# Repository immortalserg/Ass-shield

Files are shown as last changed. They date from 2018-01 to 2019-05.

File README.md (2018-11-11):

# Ass-shield
## Плата расширения для OrangePi Zero, OrangePi Zero plus, OrangePi Zero plus2, NanoPi Neo, NanoPi Neo Air, NanoPi Neo 2, NanoPi Neo Core, NanoPi Neo Core2, RaspberryPi Zero, BananaPi zero
### Функции
- Массив из 4-х микрофонов через процессор ADAU1772
- RF315/433 МГц приемник/передатчик (м.cx. SYN480R и SYN115)
- NRF24L01+
- zigbee cc2530 + cc2591
- 12 светодиодов WS2812B
- звук i2s ES9023 (только NanoPi) c усилителем 2х3Вт PAM8403 (PAM8404)
- часы реального времени DS3231
- 4 ИК светодиода для управления техникой
- диаметр 80 мм
- поддержска протокола Z-wave (USB stick или UART)
## Описание
- ИК передатчики (4 ИК диода через транзистор) подключены к GPIO26 (PA10) /NanoPi - PA0/
- 433 МГц приемник - GPIO15 (PA03) 
- 433 МГц передатчик - GPIO18 (PA18) /NanoPi PG8/
- 315 МГц приемник - GPIO12 (PA07) /NanoPi PG11/
- 315 МГц передатчик - GPIO16 (PA19) /NanoPi PG9/
- SI4432 - SPI1 (MOSI-GPIO19, MISO-GPIO21, CLK-GPIO23, NIRQ-GPIO13, NSEL-GPIO11)
- nrf24l01+ - SPI1 (MOSI-GPIO19, MISO-GPIO21, CLK-GPIO23, CS-GPIO24) /NanoPi SPI0 (MOSI-PC0, MISO-PC1, CLK-PC2, CS-PC3)/
- zigbee (cc2530) с усилителем cc2591 - UART1
- WS2812 LED - GPIO7 (PA06) 
- Часы реального времени DS3231 - i2c0
- i2c PCF8574 (P0- управление режимом записи 24LC256, P1-P4 - входы ADAU1772, P5 - MUTE  P6&P7 - Gain Select) 

Программирование ADAU1772 через i2c запись на микросхему памяти 24LC256, программирование: цифровые входы микрофонов, выходы аналоговые для OrangePi Zero, для остальных выход i2s в режиме ведомого.

J1 - питание 6-40V (1-VCC, 2-GND) на DC-DC преобразователь

J2 - DEBUG разъем для программирования cc2530 через (1-DC,2-DD,3-Reset,4-3.3V,5-GND)

J3 - питание 5В с DC-DC преобразователя (установить перемычку для питания через DC-DC преобразователь)

J4 - UART2 (1-3.3V, 2-RX, 3-TX, 4-GND) /нет для RaspberryPi Zero/

J5 - антенна NRF24L01+

J6 - i2s (1-WS, 2-CLK, 3-DIN) ADAU1772

J7 - выход на динамики (1-L+, 2-L-, 3-R+, 4-R-)

J8 - антенна zigbee (cc2530+cc2591)

### Переходная плата NanoPi Neo

J1 - переключение выхода звука 1,2-ON;3,4-OFF -- LINE / 1,2-OFF;3,4-ON -- i2s ES9023

### Переходная плата BananaPi zero, RaspberryPi Zero

J3 - переключатель i2s BananaPi Zero / RaspberryPi Zero

Для RaspberryPi Zero не используется LAN и UART2

## Изображения

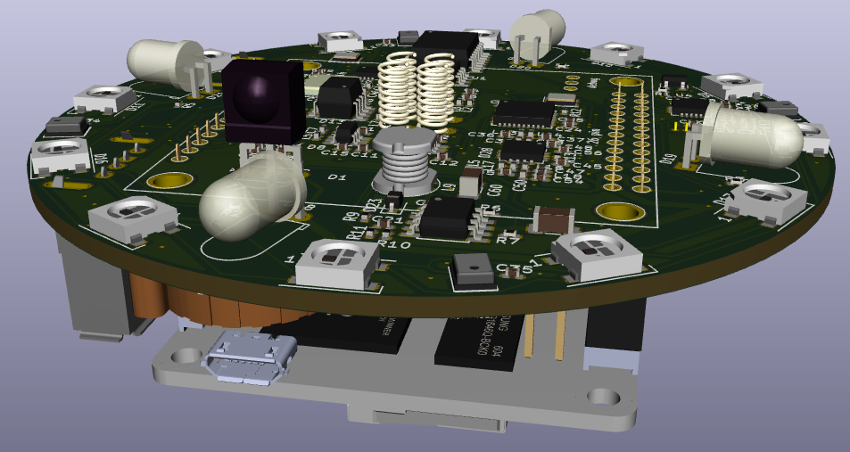
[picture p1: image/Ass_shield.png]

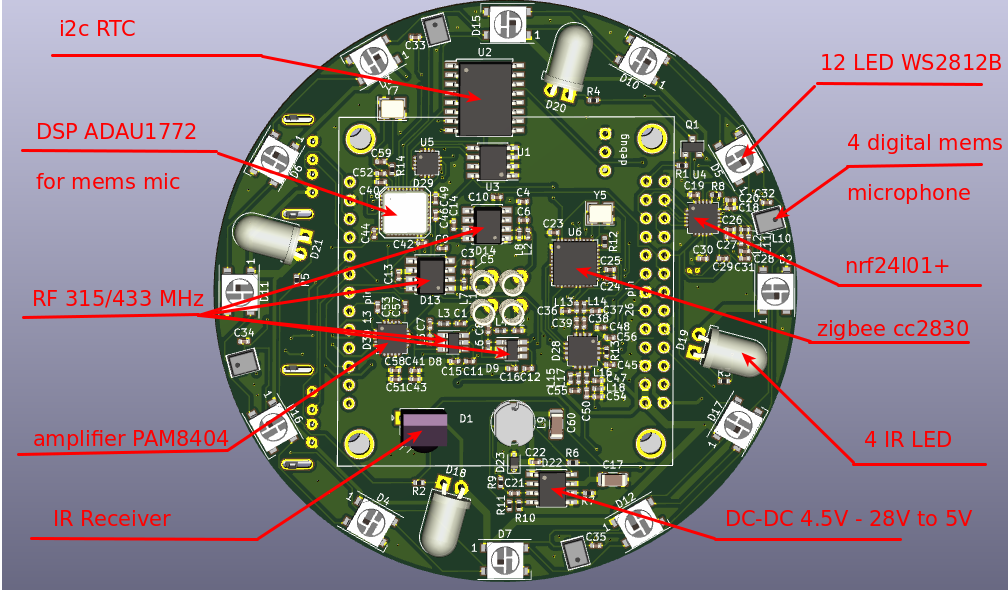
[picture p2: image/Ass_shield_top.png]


## Переходная плата для NanoPi Neo
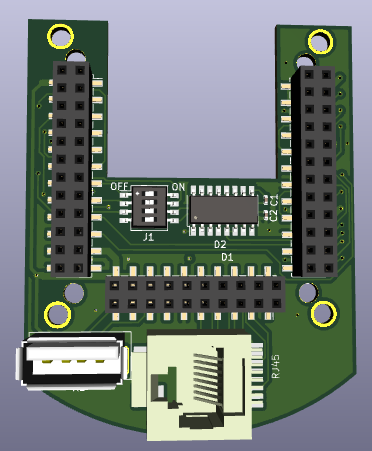
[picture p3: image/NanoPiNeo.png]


### Переходная плата BananaPi zero, RaspberryPi Zero
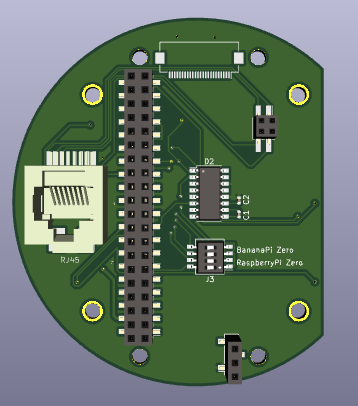
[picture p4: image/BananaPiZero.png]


## Корпус
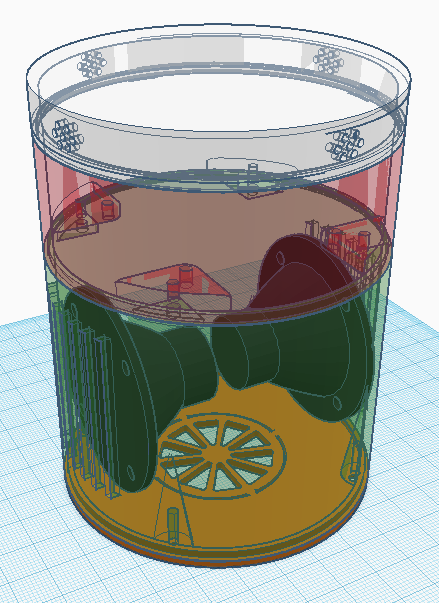
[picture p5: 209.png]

,

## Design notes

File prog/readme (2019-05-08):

AssShield.dspproj - проект в SigmaStudio

E2Prom.Hex - hex файл проекта из SigmaStudio

E2Prom.bin - bin файл для прошивки микросхемы 24cXXX

Конвертировать из HEX в BIN командой:

xxd -r -p E2Prom.Hex E2Prom.bin

# Прошивка микросхемы памяти. (https://www.richud.com/wiki/Rasberry_Pi_I2C_EEPROM_Program)

1. Разрешить запись в память микросхемы 24cXXX, для этого ногу WP подтянуть на GND (подтяжка на VCC запрещает запись)

2. Скомпилировать программу прошивки, для этого выполнить make в папке eeprog

3. Прошить bin файл:

./eeprog -f -16 -i E2Prom.bin -w 0x100 -t 5 /dev/i2c-0 0x50

4. проверить записанное в память:

i2cdump -y 0 0x50 i

или

./eeprog -xf /dev/i2c-0 0x53 -16 -r 0x00:0x200

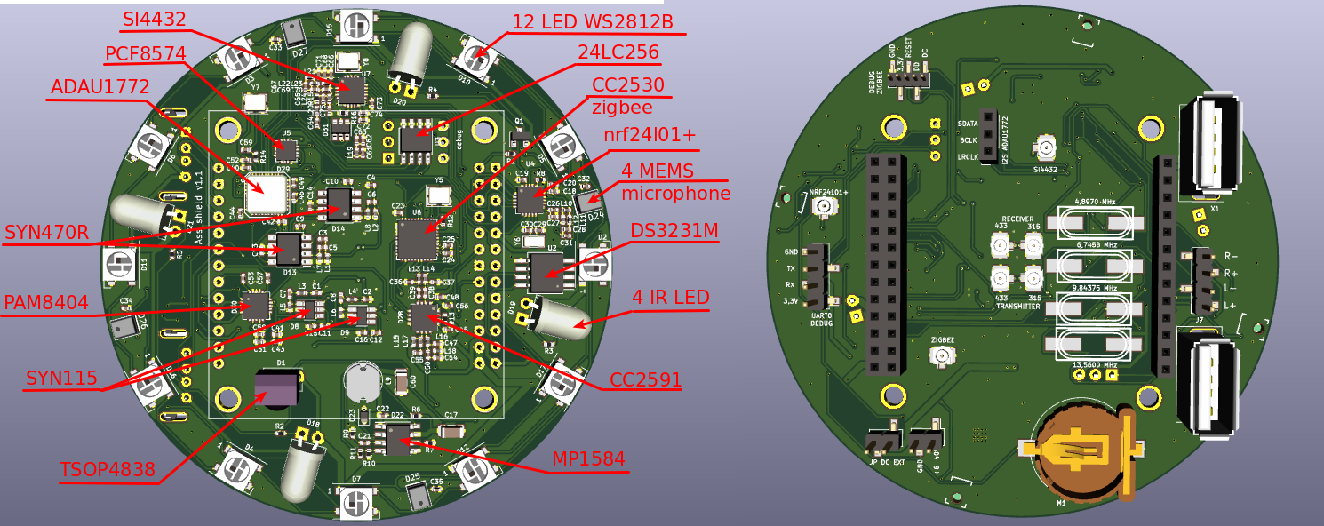
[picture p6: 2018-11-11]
image/AssShield.png

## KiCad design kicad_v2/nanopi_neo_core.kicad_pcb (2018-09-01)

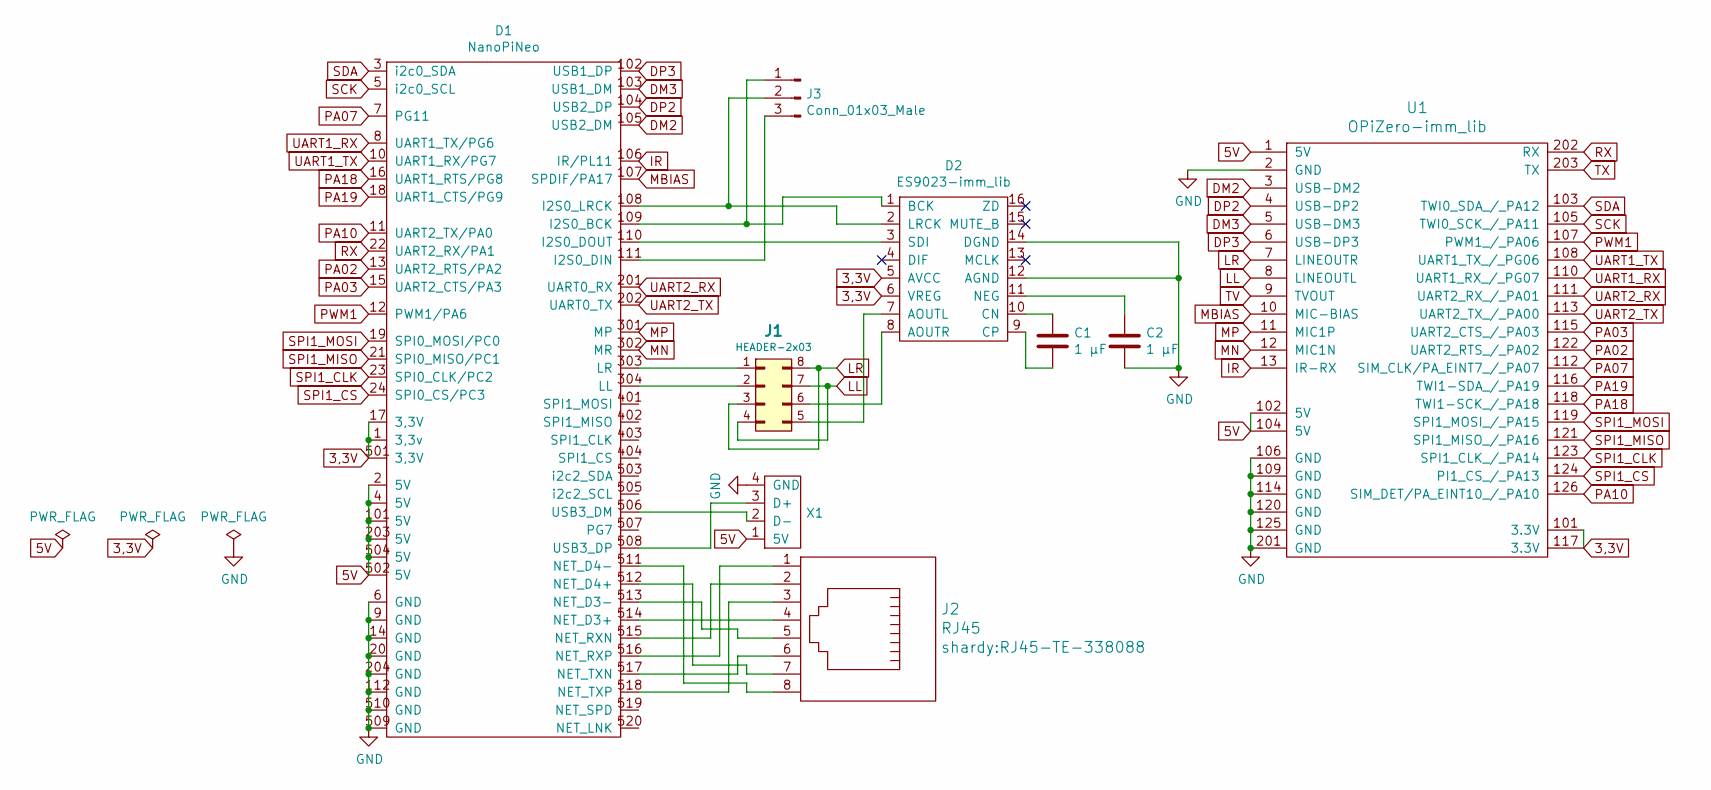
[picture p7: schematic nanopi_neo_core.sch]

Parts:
C1, C2: 1 µF; C_0402_1005Metric
D1: NanoPiNeo; NanoPiNeoAir2
D2: ES9023-imm_lib; SOP-16_4.4x10.4mm_P1.27mm
J1: HEADER-2x03; SW_DIP_SPSTx04_Slide_KingTek_DSHP04TS_W7.62mm_P1.27mm
J2: RJ45; RJ45-TE-338088
J3: Conn_01x03_Male; PinHeader_1x03_P2.54mm_Vertical_SMD_Pin1Left
U1: OPiZero-imm_lib; OPiZeroSMD
X1: USB_F1; usb_f2

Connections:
3,3V: D1.1 (3,3v), D1.17 (3,3V), D1.501 (3,3V), D2.5 (AVCC), D2.6 (VREG), U1.101 (3.3V), U1.117 (3.3V)
5V: D1.2 (5V), D1.4 (5V), D1.101 (5V), D1.203 (5V), D1.502 (5V), D1.504 (5V), U1.1 (5V), U1.102 (5V), U1.104 (5V), X1.1 (5V)
DM2: D1.105 (USB2_DM), U1.3 (USB-DM2)
DM3: D1.103 (USB1_DM), U1.5 (USB-DM3)
DP2: D1.104 (USB2_DP), U1.4 (USB-DP2)
DP3: D1.102 (USB1_DP), U1.6 (USB-DP3)
GND: C2.2, D1.6 (GND), D1.9 (GND), D1.14 (GND), D1.20 (GND), D1.112 (GND), D1.204 (GND), D1.509 (GND), D1.510 (GND), D2.12 (AGND), D2.14 (DGND), U1.2 (GND), U1.106 (GND), U1.109 (GND), U1.114 (GND), U1.120 (GND), U1.125 (GND), U1.201 (GND), X1.4 (GND)
IR: D1.106 (IR/PL11), U1.13 (IR-RX)
LL: J1.4 (P7), J1.7 (P4), U1.8 (LINEOUTL)
LR: J1.3 (P5), J1.8 (P2), U1.7 (LINEOUTR)
MBIAS: D1.107 (SPDIF/PA17), U1.10 (MIC-BIAS)
MN: D1.302 (MR), U1.12 (MIC1N)
MP: D1.301 (MP), U1.11 (MIC1P)
unnamed: C1.1, D2.10 (CN)
unnamed: C1.2, D2.9 (CP)
unnamed: C2.1, D2.11 (NEG)
unnamed: D1.108 (I2S0_LRCK), D2.2 (LRCK), J3.2
unnamed: D1.109 (I2S0_BCK), D2.1 (BCK), J3.1
unnamed: D1.110 (I2S0_DOUT), D2.3 (SDI)
unnamed: D1.111 (I2S0_DIN), J3.3
unnamed: D1.303 (LR), J1.1
unnamed: D1.304 (LL), J1.2 (P3)
unnamed: D1.506 (USB3_DM), X1.2 (D-)
unnamed: D1.508 (USB3_DP), X1.3 (D+)
unnamed: D1.511 (NET_D4-), J2.8
unnamed: D1.512 (NET_D4+), J2.7
unnamed: D1.513 (NET_D3-), J2.5
unnamed: D1.514 (NET_D3+), J2.4
unnamed: D1.515 (NET_RXN), J2.2
unnamed: D1.516 (NET_RXP), J2.1
unnamed: D1.517 (NET_TXN), J2.6
unnamed: D1.518 (NET_TXP), J2.3
unnamed: D2.7 (AOUTL), J1.5 (P8)
unnamed: D2.8 (AOUTR), J1.6
PA02: D1.13 (UART2_RTS/PA2), U1.122 (UART2_RTS_/_PA02)
PA03: D1.15 (UART2_CTS/PA3), U1.115 (UART2_CTS_/_PA03)
PA07: D1.7 (PG11), U1.112 (SIM_CLK/PA_EINT7_/_PA07)
PA10: D1.11 (UART2_TX/PA0), U1.126 (SIM_DET/PA_EINT10_/_PA10)
PA18: D1.16 (UART1_RTS/PG8), U1.118 (TWI1-SCK_/_PA18)
PA19: D1.18 (UART1_CTS/PG9), U1.116 (TWI1-SDA_/_PA19)
PWM1: D1.12 (PWM1/PA6), U1.107 (PWM1_/_PA06)
RX: D1.22 (UART2_RX/PA1), U1.202 (RX)
SCK: D1.5 (i2c0_SCL), U1.105 (TWI0_SCK_/_PA11)
SDA: D1.3 (i2c0_SDA), U1.103 (TWI0_SDA_/_PA12)
SPI1_CLK: D1.23 (SPI0_CLK/PC2), U1.123 (SPI1_CLK_/_PA14)
SPI1_CS: D1.24 (SPI0_CS/PC3), U1.124 (PI1_CS_/_PA13)
SPI1_MISO: D1.21 (SPI0_MISO/PC1), U1.121 (SPI1_MISO_/_PA16)
SPI1_MOSI: D1.19 (SPI0_MOSI/PC0), U1.119 (SPI1_MOSI_/_PA15)
UART1_RX: D1.8 (UART1_TX/PG6), U1.110 (UART1_RX_/_PG07)
UART1_TX: D1.10 (UART1_RX/PG7), U1.108 (UART1_TX_/_PG06)
UART2_RX: D1.201 (UART0_RX), U1.111 (UART2_RX_/_PA01)
UART2_TX: D1.202 (UART0_TX), U1.113 (UART2_TX_/_PA00)

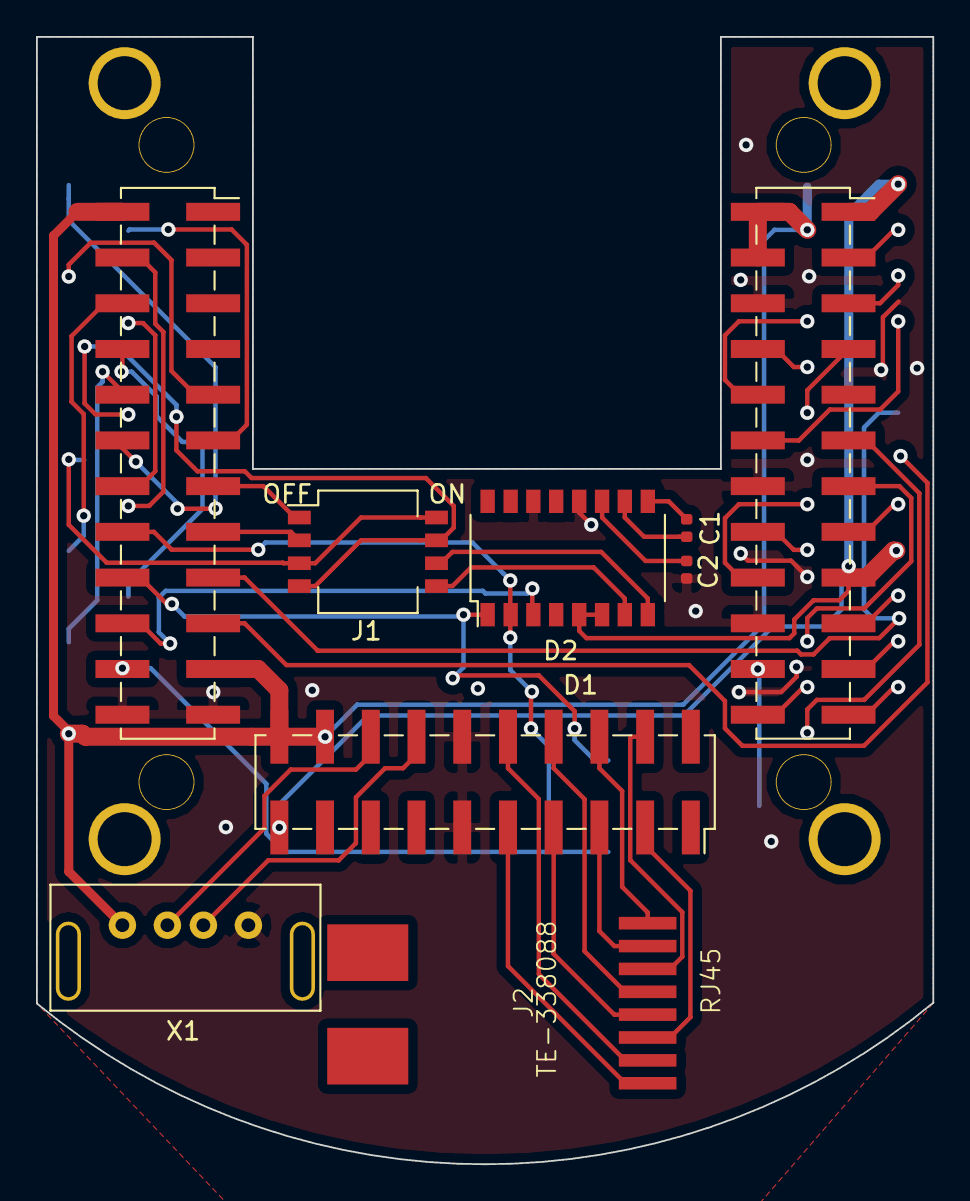
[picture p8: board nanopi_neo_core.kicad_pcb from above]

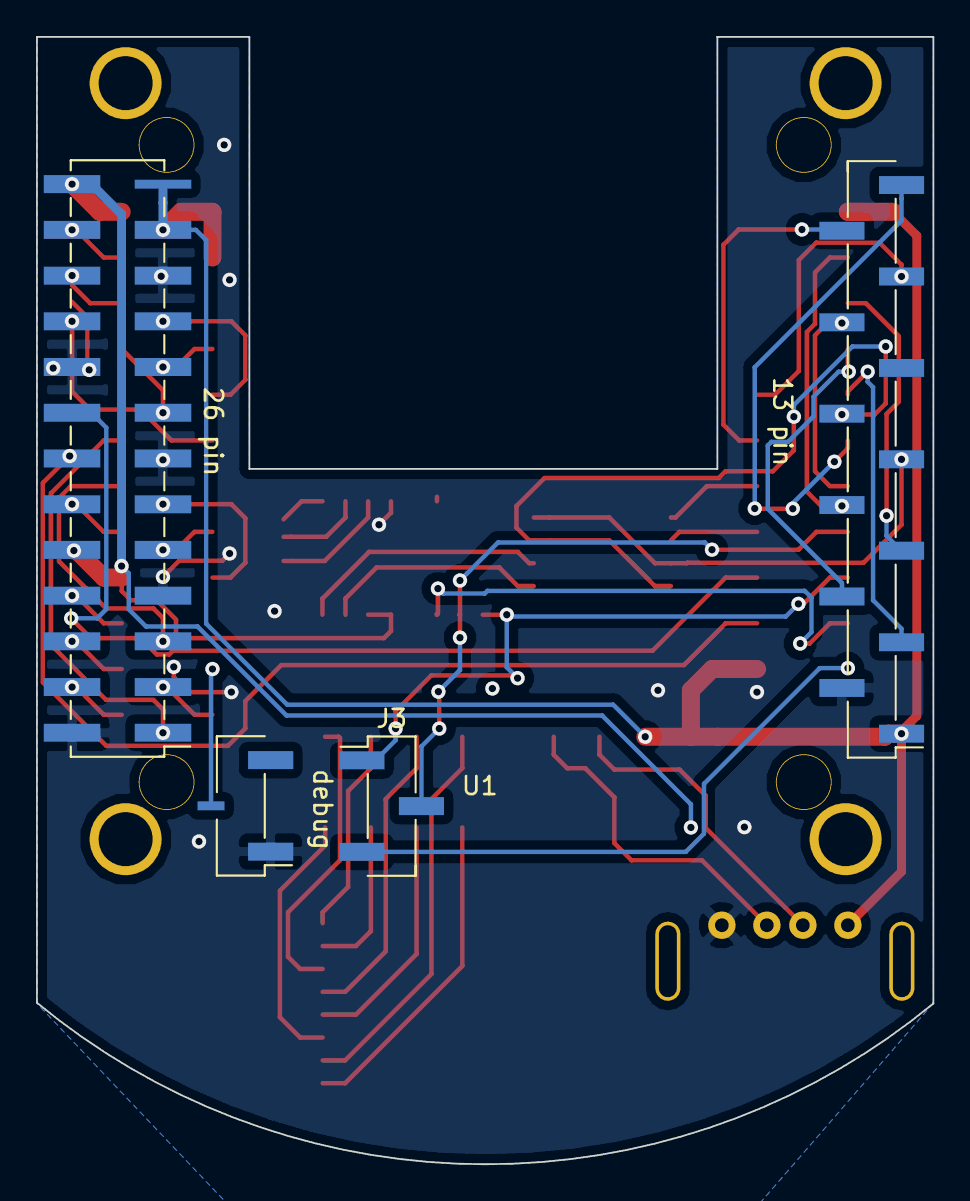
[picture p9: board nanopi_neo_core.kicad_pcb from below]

Board: 2 copper layers, 49.8 x 62.6 mm, 9 parts (2 on the bottom side), 52 nets.

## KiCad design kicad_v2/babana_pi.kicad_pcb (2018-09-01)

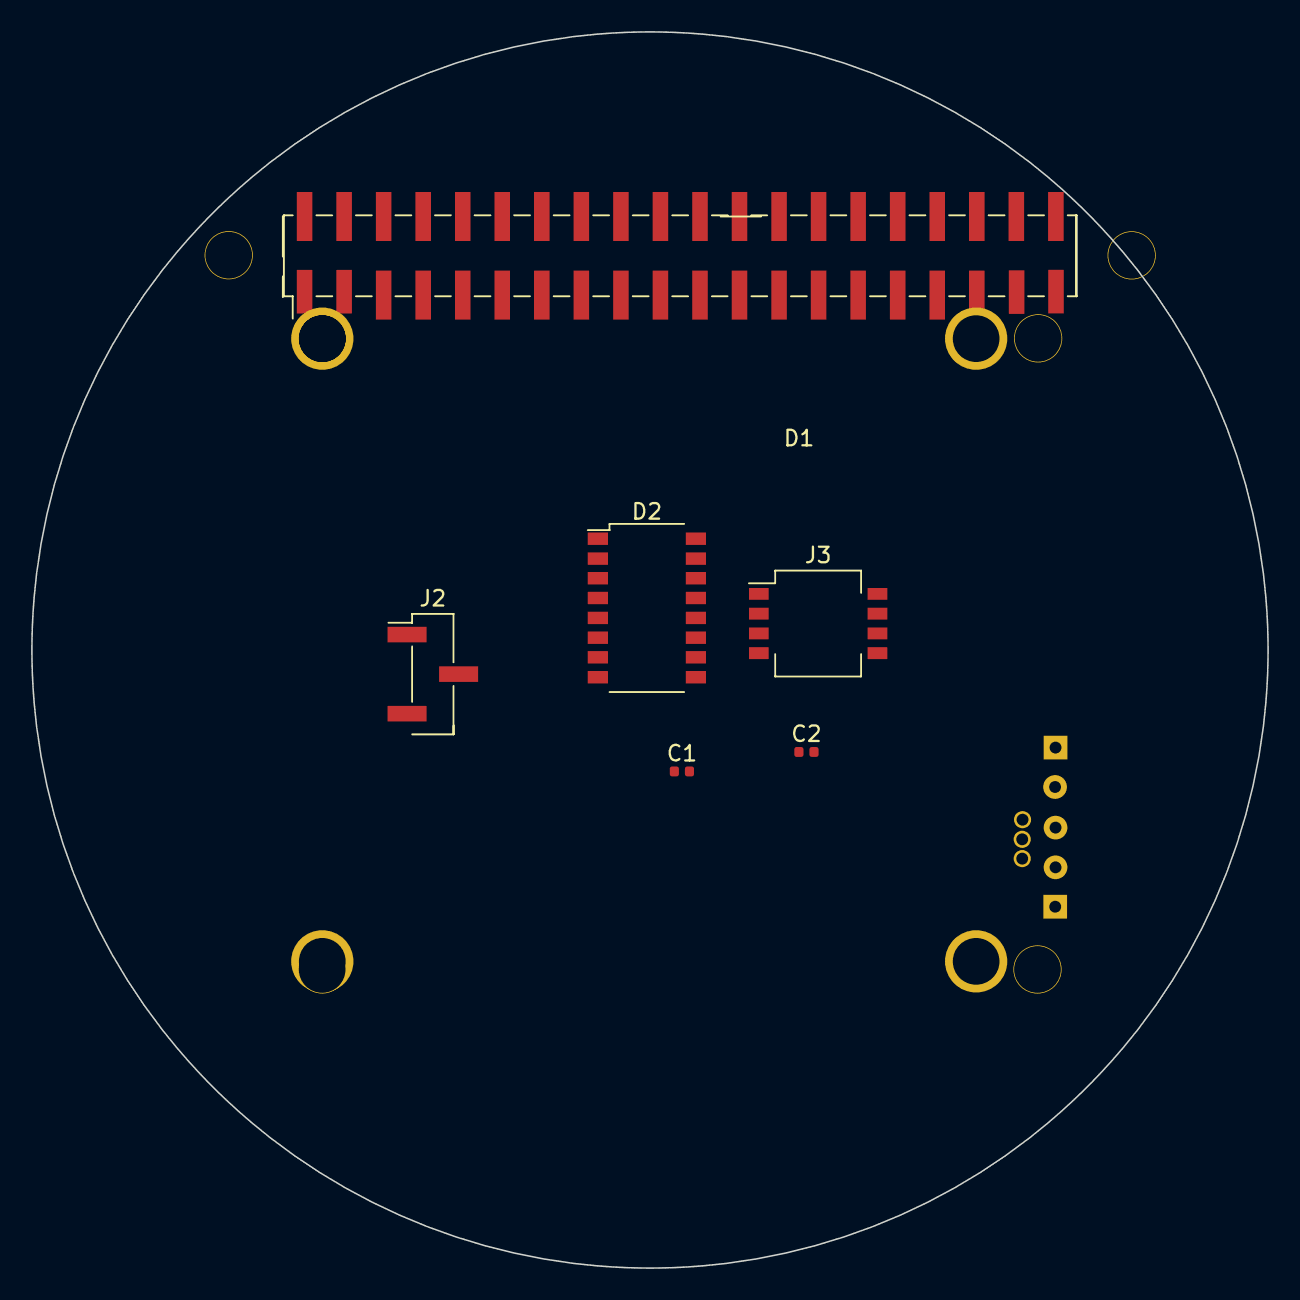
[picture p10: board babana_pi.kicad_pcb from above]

Board: 2 copper layers, 79.4 x 79.4 mm, 7 parts (1 on the bottom side), 34 nets, no tracks yet.

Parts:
C1, C2: 1 µF; C_0402_1005Metric
D1: BananaPi
D2: ES9023; SOP-16_4.4x10.4mm_P1.27mm
J2: i2s; PinHeader_1x03_P2.54mm_Vertical_SMD_Pin1Left
J3: BananaPi/RaspberryPi; SW_DIP_SPSTx04_Slide_KingTek_DSHP04TS_W7.62mm_P1.27mm
U1: OPiZero-imm_lib; OPiZeroSMD

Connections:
3,3V: D1.17, D2.5, D2.6, U1.101
5V: D1.4, U1.102, U1.104
GND: C2.2, D2.12, D2.14, U1.2, U1.106, U1.109, U1.114, U1.120, U1.125, U1.201
IR: D1.18, U1.13
LL: D2.7, U1.8
LR: D2.8, U1.7
unnamed: C1.1, D2.10
unnamed: C1.2, D2.9
unnamed: C2.1, D2.11
unnamed: D1.12, J3.8
unnamed: D1.27, J3.5
unnamed: D1.28, J3.6
unnamed: D1.35, J3.7
PA02: D1.22, U1.122
PA03: D1.15, U1.115
PA07: D1.29, U1.112
PA10: D1.26, U1.126
PA18: D1.31, U1.118
PA19: D1.33, U1.116
PWM1: D1.7, U1.107
SCK: D1.5, U1.105
SDA: D1.3, U1.103
SPI1_CLK: D1.23, U1.123
SPI1_CS: D1.24, U1.124
SPI1_MISO: D1.21, U1.121
SPI1_MOSI: D1.19, U1.119
UART1_RX: D1.10, U1.110
UART1_TX: D1.8, U1.108
UART2_RX: D1.11, U1.111
UART2_TX: D1.13, U1.113
i2s-DIN: D1.38, J2.3
i2s_CLK: D2.1, J2.2, J3.2, J3.4
i2s_SDI: D1.40, D2.3
i2s_WS: D2.2, J2.1, J3.1, J3.3

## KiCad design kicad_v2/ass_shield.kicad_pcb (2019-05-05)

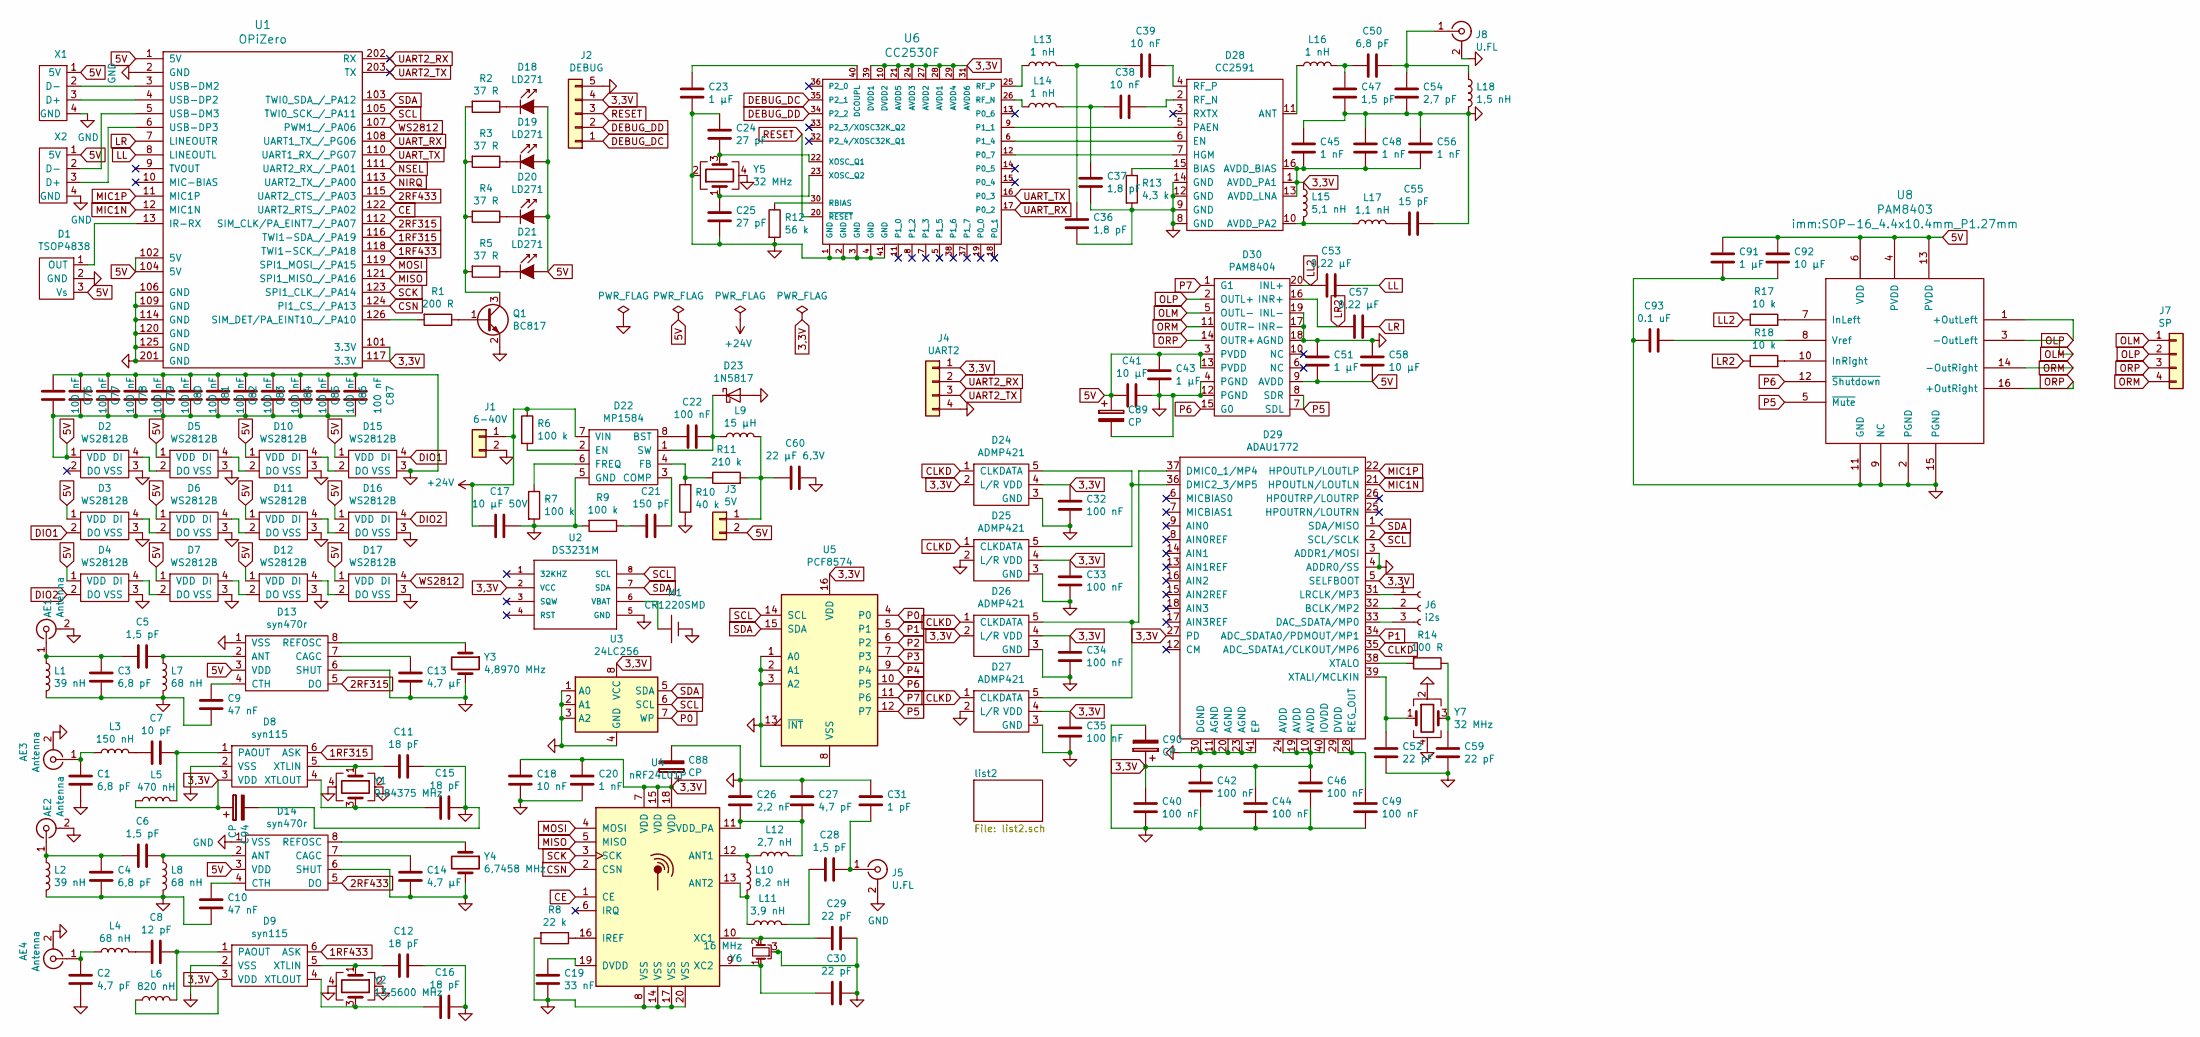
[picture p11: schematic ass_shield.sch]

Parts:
AE1, AE2, AE3, AE4: Antenna; U.FL_Hirose_U.FL-R-SMT-1_Vertical
C1, C3, C4, C50: 6,8 pF; C_0402_1005Metric
C2, C27: 4,7 pF; C_0402_1005Metric
C5, C6, C28, C47: 1,5 pF; C_0402_1005Metric
C7: 10 pF; C_0402_1005Metric
C8: 12 pF; C_0402_1005Metric
C9, C10: 47 nF; C_0402_1005Metric
C11, C12, C15, C16: 18 pF; C_0402_1005Metric
C13, C14: 4,7 µF; C_0402_1005Metric
C17: 10 µF 50V; C_1206_3216Metric
C18, C38, C39: 10 nF; C_0402_1005Metric
C19: 33 nF; C_0402_1005Metric
C20, C45, C48, C56: 1 nF; C_0402_1005Metric
C21: 150 pF; C_0402_1005Metric
C22, C32, C33, C34, C35, C40, C42, C44, C46, C49, C76, C77, C78, C79, C80, C81, C82, C83, C84, C85, C86, C87: 100 nF; C_0402_1005Metric
C23, C43, C51, C91: 1 µF; C_0402_1005Metric
C24, C25: 27 pF; C_0402_1005Metric
C26: 2,2 nF; C_0402_1005Metric
C29, C30, C52, C59: 22 pF; C_0402_1005Metric
C31: 1 pF; C_0402_1005Metric
C36, C37: 1,8 pF; C_0402_1005Metric
C41, C58, C92: 10 µF; C_0402_1005Metric
C53, C57: 0,22 µF; C_0402_1005Metric
C54: 2,7 pF; C_0402_1005Metric
C55: 15 pF; C_0402_1005Metric
C60: 22 µF 6,3V; C_1206_3216Metric
C88, C89, C90, C94: CP; C_1206_3216Metric
C93: 0.1 uF; C_0402_1005Metric
D1: TSOP4838; Vishay_MOLD-3Pin
D2, D3, D4, D5, D6, D7, D10, D11, D12, D15, D16, D17: WS2812B; ws2812b
D8, D9: syn115; SOT-23-6_Handsoldering
D13, D14: syn470r; SSOP-8_3.95x5.21x3.27mm_P1.27mm
D18, D19, D20, D21: LD271; LED_D3.0mm_Horizontal_O1.27mm_Z2.0mm_Clear
D22: MP1584; SOIC-8-1EP_3.9x4.9mm_P1.27mm_EP2.35x2.35mm
D23: 1N5817; D_SOD-323
D24, D25, D26, D27: ADMP421; ADMP421_2
D28: CC2591; QFN-16-1EP_4x4mm_P0.65mm_EP2.5x2.5mm
D29: ADAU1772; LFCSP-40-1EP
D30: PAM8404; QFN-20-1EP_4x4mm_P0.5mm_EP2.5x2.5mm
J1: 6-40V; PinHeader_1x02_P2.54mm_Vertical
J2: DEBUG; PinHeader_1x05_P1.27mm_Vertical
J3: 5V; PinHeader_1x02_P2.54mm_Vertical
J4: UART2; PinHeader_1x04_P2.54mm_Vertical_SMD_Pin1Left
J5, J8: U.FL; U.FL_Hirose_U.FL-R-SMT-1_Vertical
J6: i2s; PinSocket_1x03_P2.54mm_Vertical
J7: SP; PinHeader_1x04_P2.54mm_Vertical
L1, L2: 39 nH; L_0402_1005Metric
L3: 150 nH; L_0402_1005Metric
L4, L7, L8: 68 nH; L_0402_1005Metric
L5: 470 nH; L_0603_1608Metric
L6: 820 nH; L_0805_2012Metric
L9: 15 µH; CD54
L10: 8,2 nH; L_0402_1005Metric
L11: 3,9 nH; L_0402_1005Metric
L12: 2,7 nH; L_0402_1005Metric
L13, L14, L16: 1 nH; L_0402_1005Metric
L15: 5,1 nH; L_0402_1005Metric
L17: 1,1 nH; L_0402_1005Metric
L18: 1,5 nH; L_0402_1005Metric
M1: CR1220SMD; cr1220_smd
Q1: BC817; SOT-23
R1: 200 R; R_0402_1005Metric
R2, R3, R4, R5: 37 R; R_0402_1005Metric
R6, R7, R9: 100 k; R_0402_1005Metric
R8: 22 k; R_0402_1005Metric
R10: 40 k; R_0402_1005Metric
R11: 210 k; R_0402_1005Metric
R12: 56 k; R_0402_1005Metric
R13: 4,3 k; R_0402_1005Metric
R14: 100 R; R_0402_1005Metric
R17, R18: 10 k; R_0402_1005Metric
U1: OPiZero; OPiZero4
U2: DS3231M; SO-8_5.3x6.2mm_P1.27mm
U3: 24LC256; SOIC-8_3.9x4.9mm_P1.27mm
U4: nRF24L01P; QFN-20-1EP_4x4mm_P0.5mm_EP2.5x2.5mm
U5: PCF8574; QFN-16-1EP_3x3mm_P0.5mm_EP1.8x1.8mm
U6: CC2530F; QFN-40-1EP_6x6mm_P0.5mm_EP4.6x4.6mm
U8: PAM8403; SOP-16_4.4x10.4mm_P1.27mm
X1, X2: USB_F1; usb_f2
Y1: 9,84375 MHz; Crystal_SMD_5032-4Pin_5.0x3.2mm
Y2: 13,5600 MHz; Crystal_SMD_3225-4Pin_3.2x2.5mm
Y3: 4,8970 MHz; hc-49_smd
Y4: 6,7458 MHz; crystal_tc-26
Y5, Y7: 32 MHz; Crystal_SMD_3225-4Pin_3.2x2.5mm
Y6: 16 MHz; Crystal_SMD_3215-3Pin_3.2x1.5mm

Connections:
1RF315: D8.6 (ASK), U1.116 (TWI1-SDA_/_PA19)
1RF433: D9.6 (ASK), U1.118 (TWI1-SCK_/_PA18)
2RF315: D13.5 (DO), U1.112 (SIM_CLK/PA_EINT7_/_PA07)
2RF433: D14.5 (DO), U1.115 (UART2_CTS_/_PA03)
3,3V: C18.1, C20.1, C32.1, C33.1, C34.1, C35.1, C40.2, C42.2, C44.2, C45.1, C46.2, C48.1, C56.1, C88.1, C90.1, C94.1, D8.3 (VDD), D9.3 (VDD), D24.2 (L/R), D24.4 (VDD), D25.4 (VDD), D26.2 (L/R), D26.4 (VDD), D27.4 (VDD), D28.1 (AVDD_PA1), D28.13 (AVDD_LNA), D28.16 (AVDD_BIAS), D29.5 (SELFBOOT), D29.10 (AVDD), D29.19 (AVDD), D29.24 (AVDD), D29.27 (PD), D29.40 (IOVDD), J2.4, J4.1, L5.1, L6.1, L15.1, U1.101 (3.3V), U1.117 (3.3V), U2.2 (VCC), U3.8 (VCC), U4.7 (VDD), U4.15 (VDD), U4.18 (VDD), U5.16 (VDD), U6.10 (DVDD2), U6.21 (AVDD5), U6.24 (AVDD3), U6.27 (AVDD2), U6.28 (AVDD1), U6.29 (AVDD4), U6.31 (AVDD6), U6.39 (DVDD1)
5V: C41.2, C43.1, C51.1, C58.2, C76.1, C77.1, C78.1, C79.1, C80.1, C81.1, C82.1, C83.1, C84.1, C85.1, C86.1, C87.1, C89.1, C91.2, C92.1, D1.3 (Vs), D2.1 (VDD), D3.1 (VDD), D4.1 (VDD), D5.1 (VDD), D6.1 (VDD), D7.1 (VDD), D10.1 (VDD), D11.1 (VDD), D12.1 (VDD), D13.3 (VDD), D14.3 (VDD), D15.1 (VDD), D16.1 (VDD), D17.1 (VDD), D18.2 (A), D19.2 (A), D20.2 (A), D21.2 (A), D30.3 (PVDD), D30.9 (AVDD), D30.13 (PVDD), J3.2, U1.1 (5V), U1.102 (5V), U1.104 (5V), U8.4 (PVDD), U8.6 (VDD), U8.13 (PVDD), X1.1 (5V), X2.1 (5V)
+24V: C17.2, D22.7 (VIN), J1.1, R6.1
CE: U1.122 (UART2_RTS_/_PA02), U4.1 (CE)
CLKD: D24.1 (CLK), D25.1 (CLK), D26.1 (CLK), D27.1 (CLK), D29.35 (ADC_SDATA1/CLKOUT/MP6)
CSN: U1.124 (PI1_CS_/_PA13), U4.2 (CSN)
DEBUG_DC: J2.1, U6.35 (P2_1)
DEBUG_DD: J2.2, U6.34 (P2_2)
DIO1: D3.2 (DO), D15.4 (DI)
DIO2: D4.2 (DO), D16.4 (DI)
GND: AE1.2 (Ext), AE2.2 (Ext), AE3.2 (Ext), AE4.2 (Ext), C1.1, C2.1, C3.2, C4.2, C9.2, C10.2, C11.1, C12.1, C13.1, C14.1, C15.1, C16.1, C17.1, C18.2, C19.2, C20.2, C23.2, C24.1, C25.2, C26.1, C27.1, C29.1, C30.1, C31.1, C32.2, C33.2, C34.2, C35.2, C36.2, C37.2, C40.1, C41.1, C42.1, C43.2, C44.1, C45.2, C46.1, C47.1, C48.2, C49.1, C51.2, C52.1, C54.1, C55.1, C56.2, C58.1, C59.1, C60.1, C76.2, C77.2, C78.2, C79.2, C80.2, C81.2, C82.2, C83.2, C84.2, C85.2, C86.2, C87.2, C88.2, C89.2, C90.2, C91.1, C92.2, C93.2, C94.2, D1.2 (GND), D2.3 (VSS), D3.3 (VSS), D4.3 (VSS), D5.3 (VSS), D6.3 (VSS), D7.3 (VSS), D8.2 (VSS), D9.2 (VSS), D10.3 (VSS), D11.3 (VSS), D12.3 (VSS), D13.1 (VSS), D13.6 (SHUT), D14.1 (VSS), D14.6 (SHUT), D15.3 (VSS), D16.3 (VSS), D17.3 (VSS), D22.5 (GND), D22.9 (GND), D23.2 (A), D24.3 (GND), D25.2 (L/R), D25.3 (GND), D26.3 (GND), D27.2 (L/R), D27.3 (GND), D28.8 (GND), D28.9 (GND), D28.12 (GND), D28.14 (GND), D29.3 (ADDR1/MOSI), D29.4 (ADDR0/SS), D29.11 (AGND), D29.20 (AGND), D29.23 (AGND), D29.30 (DGND), D29.41 (EP), D30.4 (PGND), D30.12 (PGND), D30.17 (INR-), D30.18 (AGND), D30.19 (INL-), D30.21 (GND), J1.2, J2.5, J4.4, J5.2 (Ext), J8.2 (Ext), L1.2, L2.2, L7.2, L8.2, L18.2, M1.1 (-), Q1.2 (E), R7.2, R8.2, R9.2, R10.1, R12.2, R13.2, U1.2 (GND), U1.106 (GND), U1.109 (GND), U1.114 (GND), U1.120 (GND), U1.125 (GND), U1.201 (GND), U2.5 (GND), U3.1 (A0), U3.2 (A1), U3.3 (A2), U3.4 (GND), U4.8 (VSS), U4.14 (VSS), U4.17 (VSS), U4.20 (VSS), U5.1 (A0), U5.2 (A1), U5.3 (A2), U5.8 (VSS), U5.13 (~INT~), U5.17 (GND), U6.1 (GND), U6.2 (GND), U6.3 (GND), U6.4 (GND), U6.41 (GND), U8.2 (PGND), U8.9 (NC), U8.11 (GND), U8.15 (PGND), X1.4 (GND), X2.4 (GND), Y1.2, Y1.4, Y2.2, Y2.4, Y3.2, Y4.2, Y5.2, Y5.4, Y6.3, Y7.2, Y7.4; also elsewhere on the board
LL: C53.1, U1.8 (LINEOUTL)
LL2: C53.2, D30.20 (INL+), R17.1
LR: C57.1, U1.7 (LINEOUTR)
LR2: C57.2, D30.16 (INR+), R18.1
MIC1N: D29.21 (HPOUTLN/LOUTLN), U1.12 (MIC1N)
MIC1P: D29.22 (HPOUTLP/LOUTLP), U1.11 (MIC1P)
MISO: U1.121 (SPI1_MISO_/_PA16), U4.5 (MISO); also elsewhere on the board
MOSI: U1.119 (SPI1_MOSI_/_PA15), U4.4 (MOSI); also elsewhere on the board
NIRQ: U1.113 (UART2_TX_/_PA00); also elsewhere on the board
NSEL: U1.111 (UART2_RX_/_PA01); also elsewhere on the board
unnamed: AE1.1 (In), C3.1, C5.2, L1.1
unnamed: AE2.1 (In), C4.1, C6.2, L2.1
unnamed: AE3.1 (In), C1.2, L3.1
unnamed: AE4.1 (In), C2.2, L4.1
unnamed: C5.1, D13.2 (ANT), L7.1
unnamed: C6.1, D14.2 (ANT), L8.1
unnamed: C7.1, D8.1 (PAOUT), L5.2
unnamed: C7.2, L3.2
unnamed: C8.1, D9.1 (PAOUT), L6.2
unnamed: C8.2, L4.2
unnamed: C9.1, D13.4 (CTH)
unnamed: C10.1, D14.4 (CTH)
unnamed: C11.2, D8.5 (XTLIN), Y1.1
unnamed: C12.2, D9.5 (XTLIN), Y2.1
unnamed: C13.2, D13.7 (CAGC)
unnamed: C14.2, D14.7 (CAGC)
unnamed: C15.2, D8.4 (XTLOUT), Y1.3
unnamed: C16.2, D9.4 (XTLOUT), Y2.3
unnamed: C19.1, U4.19 (DVDD)
unnamed: C21.1, D22.3 (COMP)
unnamed: C21.2, R9.1
unnamed: C22.1, D22.1 (SW), D23.1 (K), L9.1
unnamed: C22.2, D22.8 (BST)
unnamed: C23.1, U6.40 (DCOUPL)
unnamed: C24.2, U6.22 (XOSC_Q1), Y5.3
unnamed: C25.1, U6.23 (XOSC_Q2), Y5.1
unnamed: C26.2, C27.2, L12.2, U4.11 (VDD_PA)
unnamed: C28.1, C31.2, J5.1 (In)
unnamed: C28.2, L11.2
unnamed: C29.2, U4.10 (XC1), Y6.2
unnamed: C30.2, U4.9 (XC2), Y6.1
unnamed: C36.1, C39.2, L13.2
unnamed: C37.1, C38.2, L14.2
unnamed: C38.1, D28.2 (RF_N)
unnamed: C39.1, D28.4 (RF_P)
unnamed: C47.2, C50.2, L16.2
unnamed: C49.2, D29.28 (REG_OUT), D29.29 (DVDD)
unnamed: C50.1, C54.2, J8.1 (In), L18.1
unnamed: C52.2, D29.39 (XTALI/MCLKIN), Y7.1
unnamed: C55.2, L17.2
unnamed: C59.2, R14.1, Y7.3
unnamed: C60.2, J3.1, L9.2, R11.2
unnamed: C93.1, U8.8 (Vref)
unnamed: D1.1 (OUT), U1.13 (IR-RX)
unnamed: D2.4 (DI), D5.2 (DO)
unnamed: D3.4 (DI), D6.2 (DO)
unnamed: D4.4 (DI), D7.2 (DO)
unnamed: D5.4 (DI), D10.2 (DO)
unnamed: D10.4 (DI), D15.2 (DO)
unnamed: D6.4 (DI), D11.2 (DO)
unnamed: D11.4 (DI), D16.2 (DO)
unnamed: D7.4 (DI), D12.2 (DO)
unnamed: D12.4 (DI), D17.2 (DO)
unnamed: D13.8 (REFOSC), Y3.1
unnamed: D14.8 (REFOSC), Y4.1
unnamed: D18.1 (K), R2.1
unnamed: D19.1 (K), R3.1
unnamed: D20.1 (K), R4.1
unnamed: D21.1 (K), R5.1
unnamed: D22.2 (EN), R6.2
unnamed: D22.4 (FB), R10.2, R11.1
unnamed: D22.6 (FREQ), R7.1
unnamed: D24.5 (DATA), D25.5 (DATA), D29.36 (DMIC2_3/MP5)
unnamed: D26.5 (DATA), D27.5 (DATA), D29.37 (DMIC0_1/MP4)
unnamed: D28.5 (PAEN), U6.9 (P1_1)
unnamed: D28.6 (EN), U6.6 (P1_4)
unnamed: D28.7 (HGM), U6.12 (P0_7)
unnamed: D28.10 (AVDD_PA2), L15.2, L17.1
unnamed: D28.11 (ANT), L16.1
unnamed: D28.15 (BIAS), R13.1
unnamed: D29.31 (LRCLK/MP3), J6.1
unnamed: D29.32 (BCLK/MP2), J6.2
unnamed: D29.33 (DAC_SDATA/MP0), J6.3
unnamed: D29.38 (XTALO), R14.2
unnamed: L10.1, L12.1, U4.12 (ANT1)
unnamed: L10.2, L11.1, U4.13 (ANT2)
unnamed: L13.1, U6.25 (RF_P)
unnamed: L14.1, U6.26 (RF_N)
unnamed: M1.2 (+), U2.6 (VBAT)
unnamed: Q1.1 (B), R1.1
unnamed: Q1.3 (C), R2.2, R3.2, R4.2, R5.2
unnamed: R1.2, U1.126 (SIM_DET/PA_EINT10_/_PA10)
unnamed: R8.1, U4.16 (IREF)
unnamed: R12.1, U6.30 (RBIAS)
unnamed: R17.2, U8.7 (InLeft)
unnamed: R18.2, U8.10 (InRight)
unnamed: U1.3 (USB-DM2), X1.2 (D-)
unnamed: U1.4 (USB-DP2), X1.3 (D+)
unnamed: U1.5 (USB-DM3), X2.2 (D-)
unnamed: U1.6 (USB-DP3), X2.3 (D+)
OLM: D30.5 (OUTL-), J7.1, U8.3 (-OutLeft)
OLP: D30.2 (OUTL+), J7.2, U8.1 (+OutLeft)
ORM: D30.11 (OUTR-), J7.4, U8.14 (-OutRight)
ORP: D30.14 (OUTR+), J7.3, U8.16 (+OutRight)
P0: U3.7 (WP), U5.4 (P0)
P1: D29.34 (ADC_SDATA0/PDMOUT/MP1), U5.5 (P1)
P5: D30.7 (SDL), D30.8 (SDR), U5.12 (P7), U8.5 (~Mute)
P6: D30.15 (G0), U5.10 (P5), U8.12 (~Shutdown)
P7: D30.1 (G1), U5.11 (P6)
RESET: J2.3, U6.20 (~RESET)
SCK: U1.123 (SPI1_CLK_/_PA14), U4.3 (SCK); also elsewhere on the board
SCL: D29.2 (SCL/SCLK), U1.105 (TWI0_SCK_/_PA11), U2.8 (SCL), U3.6 (SCL), U5.14 (SCL)
SDA: D29.1 (SDA/MISO), U1.103 (TWI0_SDA_/_PA12), U2.7 (SDA), U3.5 (SDA), U5.15 (SDA)
UART2_RX: J4.2, U1.202 (RX)
UART2_TX: J4.3, U1.203 (TX)
UART_RX: U1.108 (UART1_TX_/_PG06), U6.17 (P0_2)
UART_TX: U1.110 (UART1_RX_/_PG07), U6.16 (P0_3)
WS2812: D17.4 (DI), U1.107 (PWM1_/_PA06)

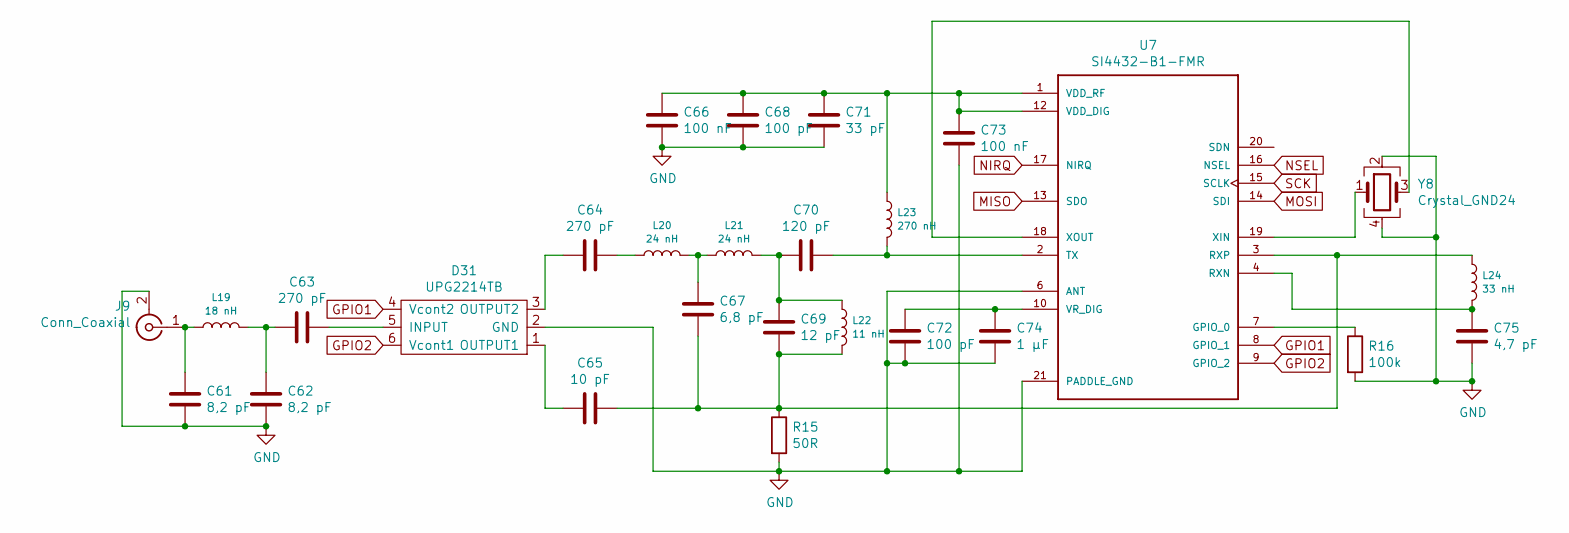
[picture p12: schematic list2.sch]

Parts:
C61, C62: 8,2 pF; C_0402_1005Metric
C63, C64: 270 pF; C_0402_1005Metric
C65: 10 pF; C_0402_1005Metric
C66, C73: 100 nF; C_0402_1005Metric
C67: 6,8 pF; C_0402_1005Metric
C68, C72: 100 pF; C_0402_1005Metric
C69: 12 pF; C_0402_1005Metric
C70: 120 pF; C_0402_1005Metric
C71: 33 pF; C_0402_1005Metric
C74: 1 µF; C_0402_1005Metric
C75: 4,7 pF; C_0402_1005Metric
D31: UPG2214TB; SOT-23-6
J9: Conn_Coaxial; U.FL_Hirose_U.FL-R-SMT-1_Vertical
L19: 18 nH; L_0402_1005Metric
L20, L21: 24 nH; L_0402_1005Metric
L22: 11 nH; L_0402_1005Metric
L23: 270 nH; L_0402_1005Metric
L24: 33 nH; L_0402_1005Metric
R15: 50R; R_0402_1005Metric
R16: 100k; R_0402_1005Metric
U7: SI4432-B1-FMR; QFN-20-1EP_4x4mm_P0.5mm_EP2.5x2.5mm
Y8: Crystal_GND24; Crystal_SMD_3225-4Pin_3.2x2.5mm

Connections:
GND: C61.1, C62.1, C66.1, C68.1, C71.1, C72.1, C73.1, C74.1, C75.1, D31.2 (GND), J9.2 (Ext), R15.2, R16.2, U7.6 (ANT), U7.21 (PADDLE_GND), Y8.2, Y8.4; also elsewhere on the board
GPIO1: D31.4 (Vcont2), U7.8 (GPIO_1)
GPIO2: D31.6 (Vcont1), U7.9 (GPIO_2)
MISO: U7.13 (SDO); also elsewhere on the board
MOSI: U7.14 (SDI); also elsewhere on the board
NIRQ: U7.17 (NIRQ); also elsewhere on the board
NSEL: U7.16 (NSEL); also elsewhere on the board
unnamed: C61.2, J9.1 (In), L19.1
unnamed: C62.2, C63.2, L19.2
unnamed: C63.1, D31.5 (INPUT)
unnamed: C64.1, L20.1
unnamed: C64.2, D31.3 (OUTPUT2)
unnamed: C65.1, C67.1, C69.1, L22.2, L24.1, R15.1, U7.3 (RXP)
unnamed: C65.2, D31.1 (OUTPUT1)
unnamed: C66.2, C68.2, C71.2, C73.2, L23.1, U7.1 (VDD_RF), U7.12 (VDD_DIG)
unnamed: C67.2, L20.2, L21.1
unnamed: C69.2, C70.2, L21.2, L22.1
unnamed: C70.1, L23.2, U7.2 (TX)
unnamed: C72.2, C74.2, U7.10 (VR_DIG)
unnamed: C75.2, L24.2, U7.4 (RXN)
unnamed: R16.1, U7.7 (GPIO_0)
unnamed: U7.18 (XOUT), Y8.3
unnamed: U7.19 (XIN), Y8.1
SCK: U7.15 (SCLK); also elsewhere on the board

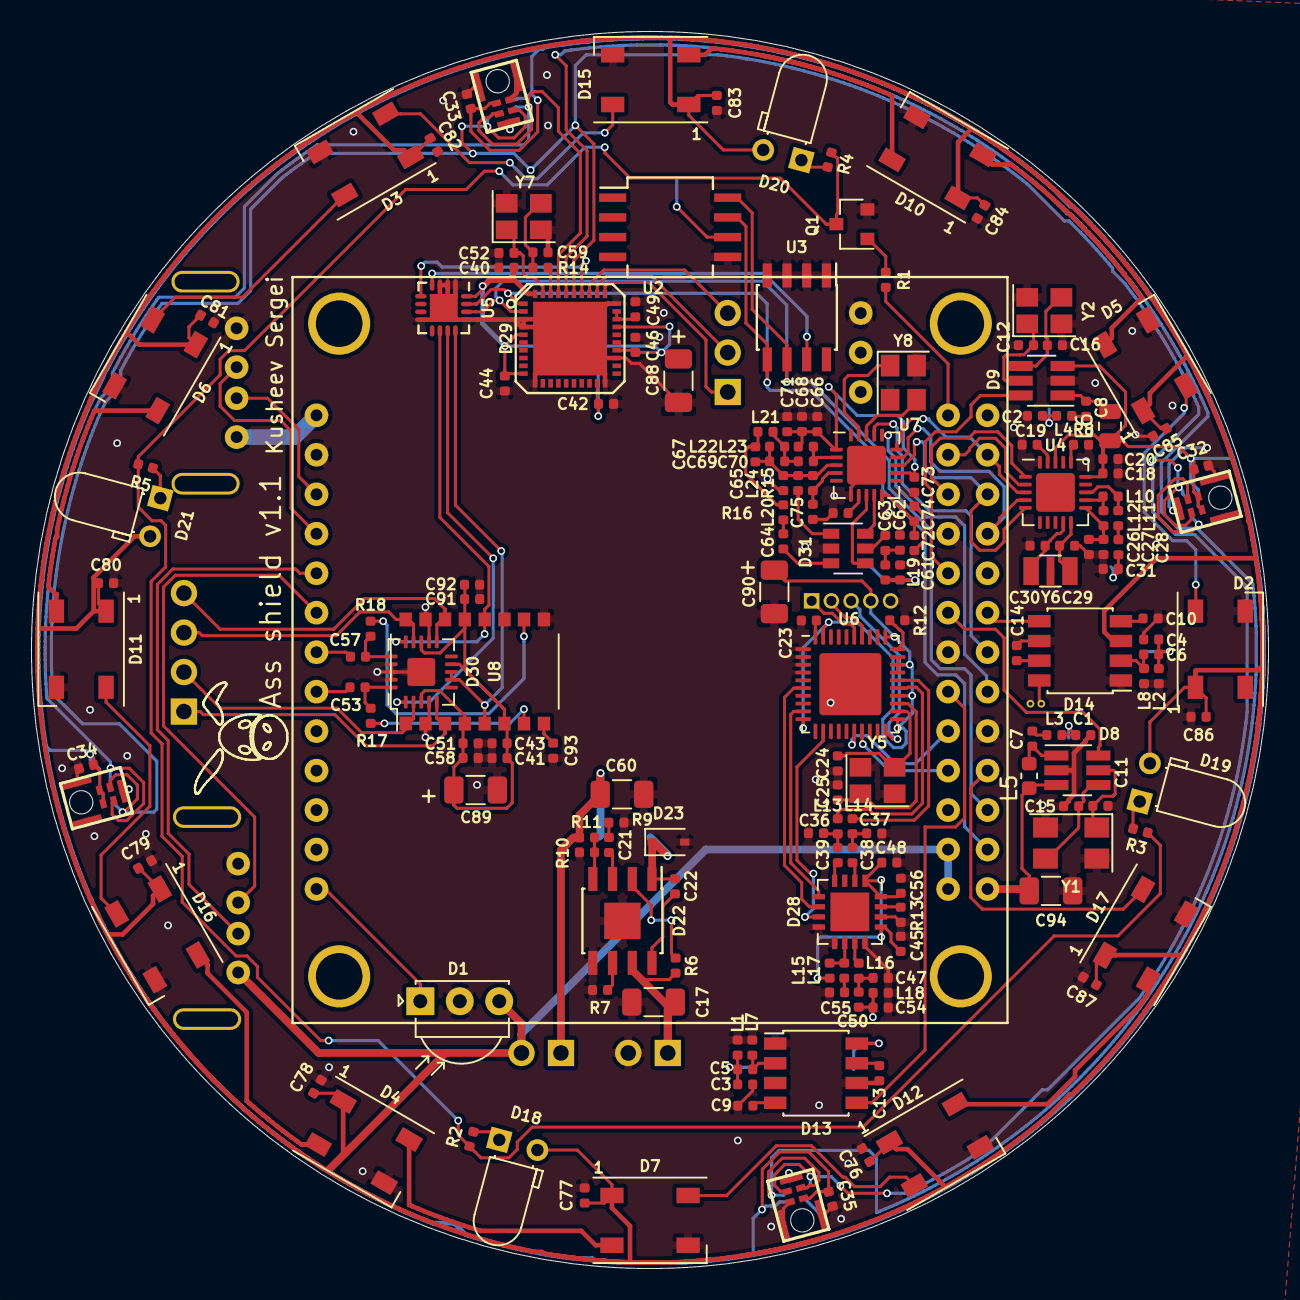
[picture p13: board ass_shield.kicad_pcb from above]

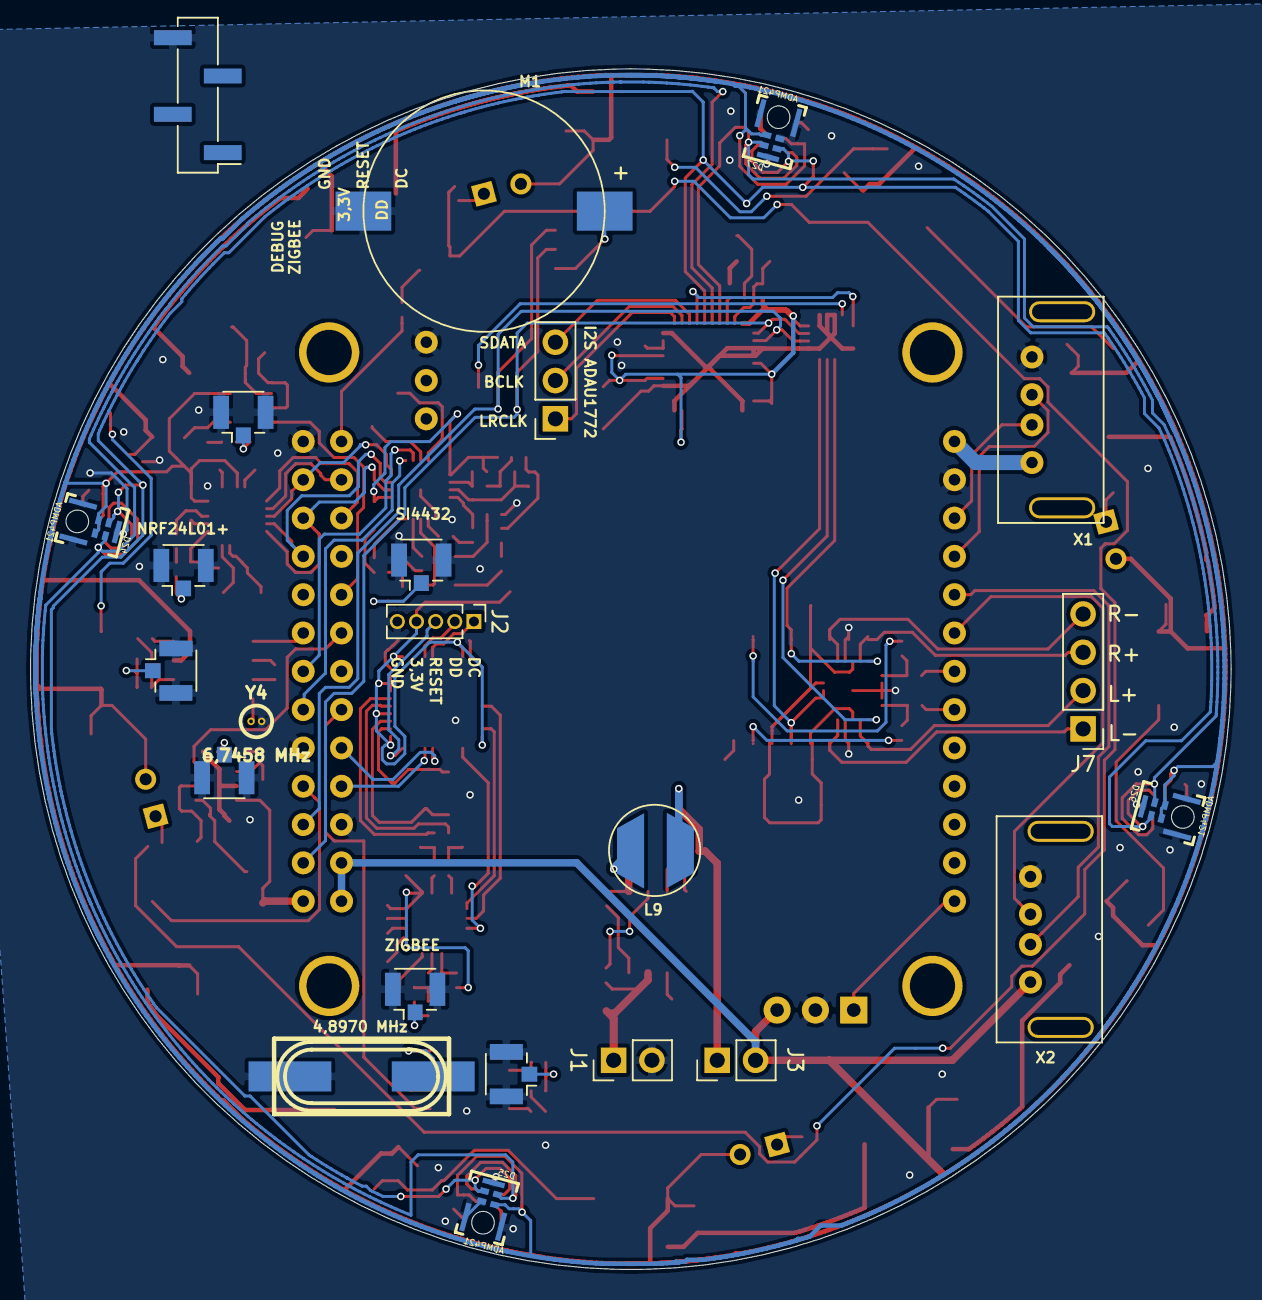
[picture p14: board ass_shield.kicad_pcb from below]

Board: 2 copper layers, 79.6 x 79.6 mm, 200 parts (19 on the bottom side), 151 nets.

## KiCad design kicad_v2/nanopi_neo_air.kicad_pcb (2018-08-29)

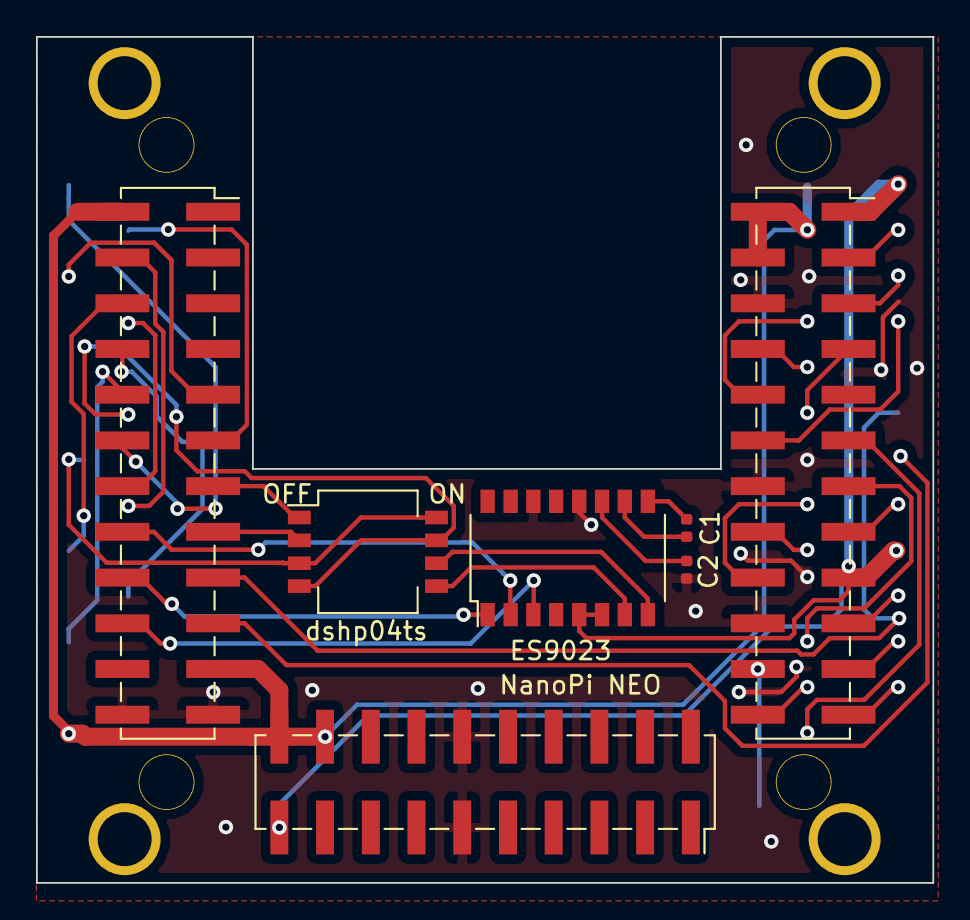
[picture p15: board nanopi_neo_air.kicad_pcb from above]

Board: 2 copper layers, 49.8 x 47.0 mm, 6 parts (1 on the bottom side), 41 nets.

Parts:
Ass Shield: OPiZero-imm_lib; OPiZeroSMD
C1, C2: 1 µF; C_0402_1005Metric
ES9023: ES9023-imm_lib; SOP-16_4.4x10.4mm_P1.27mm
NanoPi NEO: NanoPiNeo; NanoPiNeoAir2
dshp04ts: HEADER-2x03; SW_DIP_SPSTx04_Slide_KingTek_DSHP04TS_W7.62mm_P1.27mm

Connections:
3,3V: Ass Shield.101, Ass Shield.117, ES9023.5, ES9023.6, NanoPi NEO.1, NanoPi NEO.17, NanoPi NEO.501
5V: Ass Shield.1, Ass Shield.102, Ass Shield.104, NanoPi NEO.2, NanoPi NEO.4, NanoPi NEO.101, NanoPi NEO.203, NanoPi NEO.502, NanoPi NEO.504
DM2: Ass Shield.3, NanoPi NEO.105
DM3: Ass Shield.5, NanoPi NEO.103
DP2: Ass Shield.4, NanoPi NEO.104
DP3: Ass Shield.6, NanoPi NEO.102
GND: Ass Shield.2, Ass Shield.106, Ass Shield.109, Ass Shield.114, Ass Shield.120, Ass Shield.125, Ass Shield.201, C2.2, ES9023.12, ES9023.14, NanoPi NEO.6, NanoPi NEO.9, NanoPi NEO.14, NanoPi NEO.20, NanoPi NEO.112, NanoPi NEO.204, NanoPi NEO.509, NanoPi NEO.510
IR: Ass Shield.13, NanoPi NEO.106
LL: Ass Shield.8, dshp04ts.4, dshp04ts.7
LR: Ass Shield.7, dshp04ts.3, dshp04ts.8
MBIAS: Ass Shield.10, NanoPi NEO.107
MN: Ass Shield.12, NanoPi NEO.302
MP: Ass Shield.11, NanoPi NEO.301
unnamed: C1.1, ES9023.10
unnamed: C1.2, ES9023.9
unnamed: C2.1, ES9023.11
unnamed: ES9023.2, NanoPi NEO.108
unnamed: ES9023.1, NanoPi NEO.109
unnamed: ES9023.3, NanoPi NEO.110
unnamed: NanoPi NEO.303, dshp04ts.1
unnamed: NanoPi NEO.304, dshp04ts.2
unnamed: ES9023.7, dshp04ts.5
unnamed: ES9023.8, dshp04ts.6
PA02: Ass Shield.122, NanoPi NEO.13
PA03: Ass Shield.115, NanoPi NEO.15
PA07: Ass Shield.112, NanoPi NEO.7
PA10: Ass Shield.126, NanoPi NEO.11
PA18: Ass Shield.118, NanoPi NEO.16
PA19: Ass Shield.116, NanoPi NEO.18
PWM1: Ass Shield.107, NanoPi NEO.12
RX: Ass Shield.202, NanoPi NEO.22
SCK: Ass Shield.105, NanoPi NEO.5
SDA: Ass Shield.103, NanoPi NEO.3
SPI1_CLK: Ass Shield.123, NanoPi NEO.23
SPI1_CS: Ass Shield.124, NanoPi NEO.24
SPI1_MISO: Ass Shield.121, NanoPi NEO.21
SPI1_MOSI: Ass Shield.119, NanoPi NEO.19
UART1_RX: Ass Shield.110, NanoPi NEO.8
UART1_TX: Ass Shield.108, NanoPi NEO.10
UART2_RX: Ass Shield.111, NanoPi NEO.201
UART2_TX: Ass Shield.113, NanoPi NEO.202

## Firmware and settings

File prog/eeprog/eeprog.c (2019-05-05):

/***************************************************************************
    copyright            : (C) by 2003-2004 Stefano Barbato
    email                : stefano@codesink.org
    
    Copyright (C) 2011 by Kris Rusocki <kszysiu@gmail.com>
    - usage/strings cleanup
    - misc cleanup: use "static" keyword where appropriate
    - misc cleanup: have confirm_action() return void
    - support custom input and output files
    - support user-defined write cycle time
    - ensure that stdin is a terminal when operating w/o -f
    - do not allow reading data from a terminal w/o -f
    - perform complete input validation before taking action
    - use dedicated exit code when opening I2C device fails

    $Id: eeprog.c,v 1.28 2004/02/29 11:06:41 tat Exp $
 ***************************************************************************/

/***************************************************************************
 *                                                                         *
 *   This program is free software; you can redistribute it and/or modify  *
 *   it under the terms of the GNU General Public License as published by  *
 *   the Free Software Foundation; either version 2 of the License, or     *
 *   (at your option) any later version.                                   *
 *                                                                         *
 ***************************************************************************/
#include <stdio.h>
#include <fcntl.h>
#include <getopt.h>
#include <unistd.h>
#include <stdlib.h>
#include <errno.h>
#include <string.h>
#include <sys/types.h>
#include <sys/stat.h>
#include "24cXX.h"

#define VERSION 	"0.7.6-tear12"

#define ENV_DEV		"EEPROG_DEV"
#define ENV_I2C_ADDR	"EEPROG_I2C_ADDR"

static int g_quiet;

#define usage_if(a) do { do_usage_if( a , __LINE__); } while(0);
static void do_usage_if(int b, int line)
{
const static char *eeprog_usage = 
"eeprog " VERSION ", a 24Cxx EEPROM reader/writer\n"
"Copyright (c) 2003-2004 by Stefano Barbato - All rights reserved.\n"
"Copyright (c) 2011 by Kris Rusocki - All rights reserved.\n"
"Usage:\n"
"\teeprog [-fqxd] [-16|-8] -r addr[:count] [-o file] /dev/i2c-N  i2c-address\n" 
"\teeprog [-fqd] [-16|-8] -w addr [-i file] [-t tWC] /dev/i2c-N  i2c-address\n" 
"\teeprog -h\n"
"\n"
"  Address modes: \n"
"	-8		Use 8bit address mode for 24c0x...24C16 [default]\n"
"	-16		Use 16bit address mode for 24c32...24C256\n"
"  Actions: \n"
"	-r addr[:count]	Read [count] (1 if omitted) bytes from [addr]\n" 
"			and print them to the standard output (or file\n"
"			specified by -o)\n"
"	-w addr		Write stdin (or file specified by -i) starting\n"
"			at address [addr] of the EEPROM\n"
"	-h		Print this help\n"
"  Options: \n"
"	-i file		Read input from [file] (for use with -w)\n"
"	-o file		Write output to [file] (for use with -r)\n"
"	-x		Set hex output mode\n" 
"	-d		Dummy mode, display what *would* have been done\n" 
"	-f		Disable warnings and don't ask confirmation\n"
"	-q		Quiet mode\n"
"	-t tWC		Define chip's write cycle time to [tWC] miliseconds\n"
"\n"
"The following environment variables could be set instead of the command\n"
"line arguments:\n"
"	EEPROG_DEV		device name(/dev/i2c-N)\n"
"	EEPROG_I2C_ADDR		i2c-address\n"
"\n"
"	Examples\n"
"	1- read 64 bytes from the EEPROM at address 0x54 on bus 0 starting\n"
"	   at address 123 (decimal)\n"
"		eeprog /dev/i2c-0 0x54 -r 123:64\n"
"	2- prints the hex codes of the first 32 bytes read from bus 1 \n"
"	   at address 0x22\n"
"		eeprog /dev/i2c-1 0x51 -x -r 0x22:0x20\n"
"	3- write the current timestamp at address 0x200 of the EEPROM on \n"
"	   bus 0 at address 0x33 \n"
"		date | eeprog /dev/i2c-0 0x33 -w 0x200 -f\n";

	if(!b)
		return;
	fprintf(stderr, "%s\n[line %d]\n", eeprog_usage, line);
	exit(1);
}


#define die_if3(a, msg, code) do { do_die_if( a , msg, __LINE__, code); } while(0)
#define die_if(a, msg) die_if3(a, msg, 1)
static void do_die_if(int b, char* msg, int line, int exitcode)
{
	if(!b)
		return;
	fprintf(stderr, "Error at line %d: %s\n", line, msg);
	//fprintf(stderr, "	sysmsg: %s\n", strerror(errno));
	exit(exitcode);
}

#define print_info(args...) do { if(!g_quiet) fprintf(stderr, args); } while(0)

static int parse_arg(char *arg, int* paddr, int *psize)
{
	char *end;
	unsigned int out_paddr, out_psize;

	if(arg[0] == '\0')
		return -1;

	out_paddr = strtol(arg, &end, 0);
	if(*end == '\0')
	{
		if(paddr)
			*paddr = out_paddr;
		return 1;
	}

	if(*end != ':')
		return -1;

	if(end[1] == '\0')
		return -1;

	out_psize = strtol(end + 1, &end, 0);
	if(*end == '\0')
	{
		if (paddr)
			*paddr = out_paddr;
		if (psize)
			*psize = out_psize;
		return 2;
	}

	return -1;
}

static void confirm_action()
{
	fprintf(stderr, 
	"\n"
	"____________________________WARNING____________________________\n"
	"Erroneously writing to a system EEPROM (like DIMM SPD modules)\n"
	"may break your system.  In such event, it will NOT boot anymore\n"
	"and you may not be able to fix it.\n"
	"\n"
	"Reading from 8bit EEPROMs (like that in your DIMM) while using\n"
	"-16 option can also UNEXPECTEDLY write to them so be sure to\n"
	"use -16 option ONLY when required.\n"
	"\n"
	"Use -f to disable this warning message\n"
	"\n"
	"Press ENTER to continue or hit CTRL-C to exit\n"
	"\n"
	);

	getchar();
}

static int read_from_eeprom(struct eeprom *e, FILE *fp, int addr, int size, int hex)
{
	int ch, i;
	for(i = 0; i < size; ++i, ++addr)
	{
		die_if((ch = eeprom_read_byte(e, addr)) < 0, "read error");
		if(hex)
		{
			if( (i % 16) == 0 ) 
				fprintf(fp, "\n %.4x|  ", addr);
			else if( (i % 8) == 0 ) 
				fprintf(fp, "  ");
			fprintf(fp, "%.2x ", ch);
		} else 
			putc(ch, fp);
	}
	if(hex)
		fprintf(fp, "\n\n");
	fflush(fp);
	return 0;
}

static int write_to_eeprom(struct eeprom *e, FILE *fp, int addr)
{
	int c;
	while((c = fgetc(fp)) != EOF)
	{
		print_info(".");
		fflush(stdout);
		die_if(eeprom_write_byte(e, addr++, c), "write error");
	}
	print_info("\n\n");
	return 0;
}

int main(int argc, char** argv)
{
	struct eeprom e;
	int ret, op, i2c_addr, memaddr, size, want_hex, dummy, force, sixteen, write_cycle_time;

	char *input_file, *output_file;
	FILE *input_fp, *output_fp;

	char *device, *arg = 0, *i2c_addr_s;
	struct stat st;
	int eeprom_type = 0;

	op = want_hex = dummy = force = sixteen = write_cycle_time = 0;
	size = 1; // default
	g_quiet = 0;

	input_file = output_file = NULL;
	input_fp = stdin;
	output_fp = stdout;

	while((ret = getopt(argc, argv, "1:8fr:qhw:xdt:i:o:")) != -1)
	{
		switch(ret)
		{
		case '1':
			usage_if(*optarg != '6' || strlen(optarg) != 1);
			die_if(eeprom_type, "EEPROM type switch (-8 or -16) used twice");
			eeprom_type = EEPROM_TYPE_16BIT_ADDR;	
			break;
		case 'x':
			want_hex++;
			break;
		case 'd':
			dummy++;
			break;
		case '8':
			die_if(eeprom_type, "EEPROM type switch (-8 or -16) used twice");
			eeprom_type = EEPROM_TYPE_8BIT_ADDR;
			break;
		case 'f':
			force++;
			break;
		case 'q':
			g_quiet++;
			break;
		case 'h':
			usage_if(1);
			break;
		case 't':
			die_if(parse_arg(optarg, &write_cycle_time, NULL) != 1 || write_cycle_time < 0, "-t -- invalid argument");
			break;
		case 'i':
			input_file = optarg;
			break;
		case 'o':
			output_file = optarg;
			break;
		default:
			die_if(op != 0, "Both read and write requested"); 
			arg = optarg;
			op = ret;
		}
	}
	if(!eeprom_type)
		eeprom_type = EEPROM_TYPE_8BIT_ADDR; // default

	usage_if(op == 0); // no switches 
	// set device and i2c_addr reading from cmdline or env
	device = i2c_addr_s = 0;
	switch(argc - optind)
	{
	case 0:
		device = getenv(ENV_DEV);
		i2c_addr_s = getenv(ENV_I2C_ADDR);
		break;
	case 1:
		if(stat(argv[optind], &st) != -1)
		{
			device = argv[optind];
			i2c_addr_s = getenv(ENV_I2C_ADDR);
		} else {
			device = getenv(ENV_DEV);
			i2c_addr_s = argv[optind];
		}
		break;
	case 2:
		device = argv[optind++];
		i2c_addr_s = argv[optind];
		break;
	default:
		usage_if(1);
	}
	usage_if(!device || !i2c_addr_s);
	die_if(parse_arg(i2c_addr_s, &i2c_addr, NULL) != 1 || i2c_addr < 0, "I2C address -- invalid argument");
	ret = parse_arg(arg, &memaddr, &size);
	die_if(op == 'r' && (ret == -1 || memaddr < 0 || size < 0), "-r -- invalid argument");
	die_if(op == 'w' && (ret != 1 || memaddr < 0), "-w -- invalid argument");

	print_info("eeprog %s, a 24Cxx EEPROM reader/writer\n", VERSION);
	print_info("Copyright (c) 2003-2004 by Stefano Barbato - All rights reserved.\n");
	print_info("Copyright (c) 2011 by Kris Rusocki - All rights reserved.\n");
	print_info("  Bus: %s, Address: 0x%02x, Mode: %dbit\n", 
			device, i2c_addr, 
			(eeprom_type == EEPROM_TYPE_8BIT_ADDR ? 8 : 16) );
	if(op == 'r')
	{
		print_info("  Operation: read %d bytes from offset %d, Output file: %s\n",
				size, memaddr, output_file ? output_file : "<stdout>");
	} else {
		print_info("  Operation: write at offset %d, Input file: %s\n",
				memaddr, input_file ? input_file : "<stdin>");
		if(write_cycle_time != 0)
			print_info("  Write cycle time: %d milliseconds\n", write_cycle_time);
	}

	if(dummy)
	{
		fprintf(stderr, "Dummy mode selected, nothing done.\n");
		return 0;
	}

	if (input_file) {
		die_if((input_fp = fopen(input_file, "rb")) == NULL,
			"unable to open input file "
			"(check that the file exists and that it's readable)");
	} else {
		input_file = "<stdin>";
	}

	if (output_file) {
		die_if((output_fp = fopen(output_file, "wb")) == NULL,
			"unable to create output file "
			"(check that you have permissions to write the file)");
	} else {
		output_file = "<stdout>";
	}

	die_if3(eeprom_open(device, i2c_addr, eeprom_type, write_cycle_time, &e) < 0, 
			"unable to open eeprom device file "
			"(check that the file exists and that it's readable)",
			2);
	switch(op)
	{
	case 'r':
		if(force == 0) {
			/* Confirmation must come from a terminal */
			die_if(isatty(0) == 0,
				"stdin is not a terminal"
			);
			confirm_action();
		}
		print_info("  Reading %d bytes from 0x%x\n", size, memaddr);
		read_from_eeprom(&e, output_fp, memaddr, size, want_hex);
		break;
	case 'w':
		if(force == 0) {
			/* Don't read data from a terminal */
			die_if(isatty(fileno(input_fp)) == 1,
				"refusing to read data from a terminal\n"
				"\n"
				"Use -i to provide input file or -f to force."
			);

			/* Confirmation must come from a terminal */
			die_if(isatty(0) == 0,
				"stdin is not a terminal"
				"\n"
				"Use -f to force."
			);
			confirm_action();
		}
		print_info("  Writing %s starting at address 0x%x\n",
			input_file, memaddr);
		write_to_eeprom(&e, input_fp, memaddr);
		break;
	default:
		usage_if(1);
		exit(1);
	}
	eeprom_close(&e);

	return 0;
}
